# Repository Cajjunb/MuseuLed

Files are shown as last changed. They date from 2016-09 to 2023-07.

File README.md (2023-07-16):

# PCB Circuit Specification

## Description
The PCB Circuit Specification project aims to provide detailed specifications and guidelines for designing printed circuit boards (PCBs). This project covers various aspects of PCB design, including component placement, trace routing, and manufacturing considerations. The project is for a Computer Vision application and for the #ART15 fair of computer art.

## Features
- Comprehensive guidelines for PCB component placement
- Detailed trace routing specifications
- Design rules for ensuring signal integrity and minimizing noise
- Manufacturing considerations and best practices
- Sample PCB designs and case studies for reference

## Requirements
- PCB design software (e.g., Eagle, Altium Designer)
- Understanding of electronic components and circuit design principles
- Knowledge of PCB manufacturing processes

## Credits
This project is maintained by Leandro Ramalho Motta Ferreira. If you have any questions or inquiries, please contact [cajjunb@gmail.com].

## License
This project is licensed under the [MIT License](LICENSE)

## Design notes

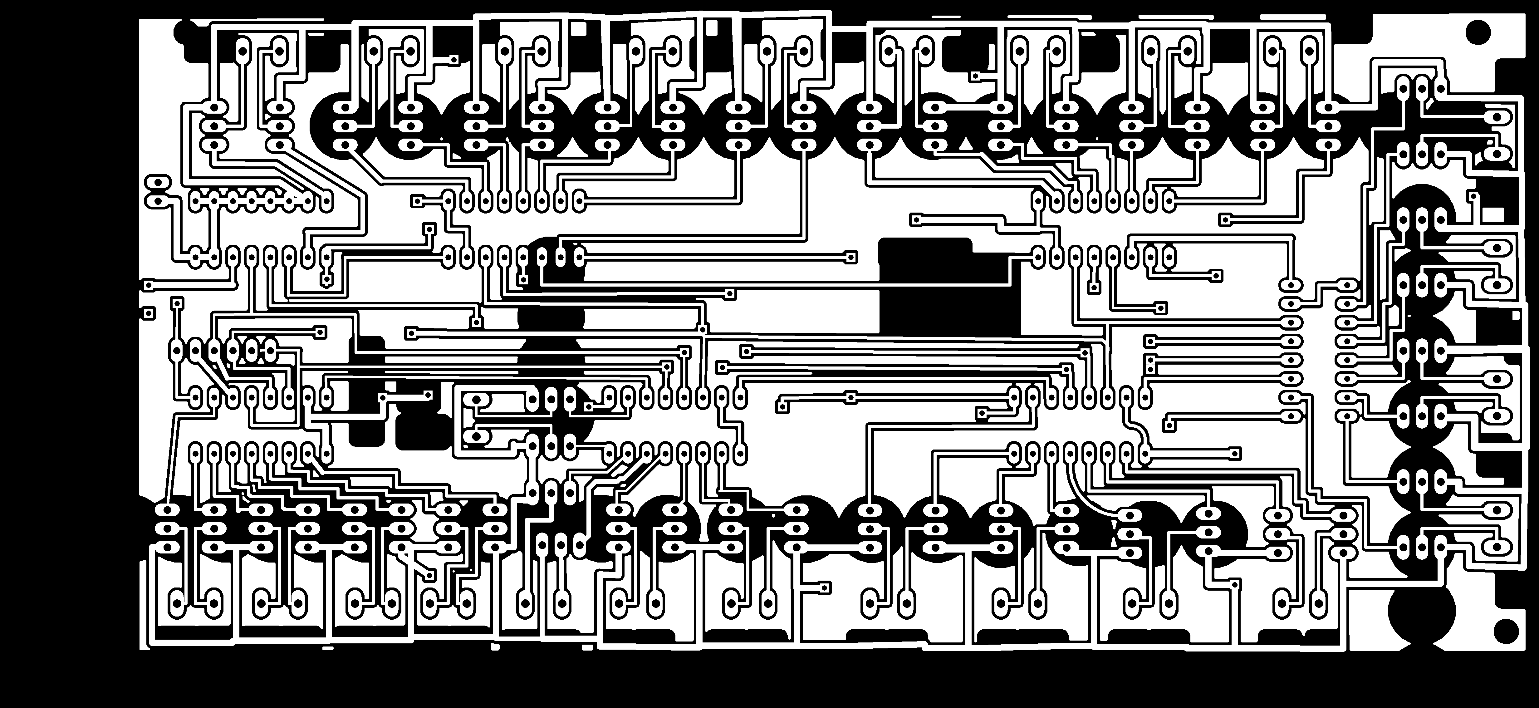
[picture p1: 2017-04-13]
circuito2/Impressão/!eagle_export.png

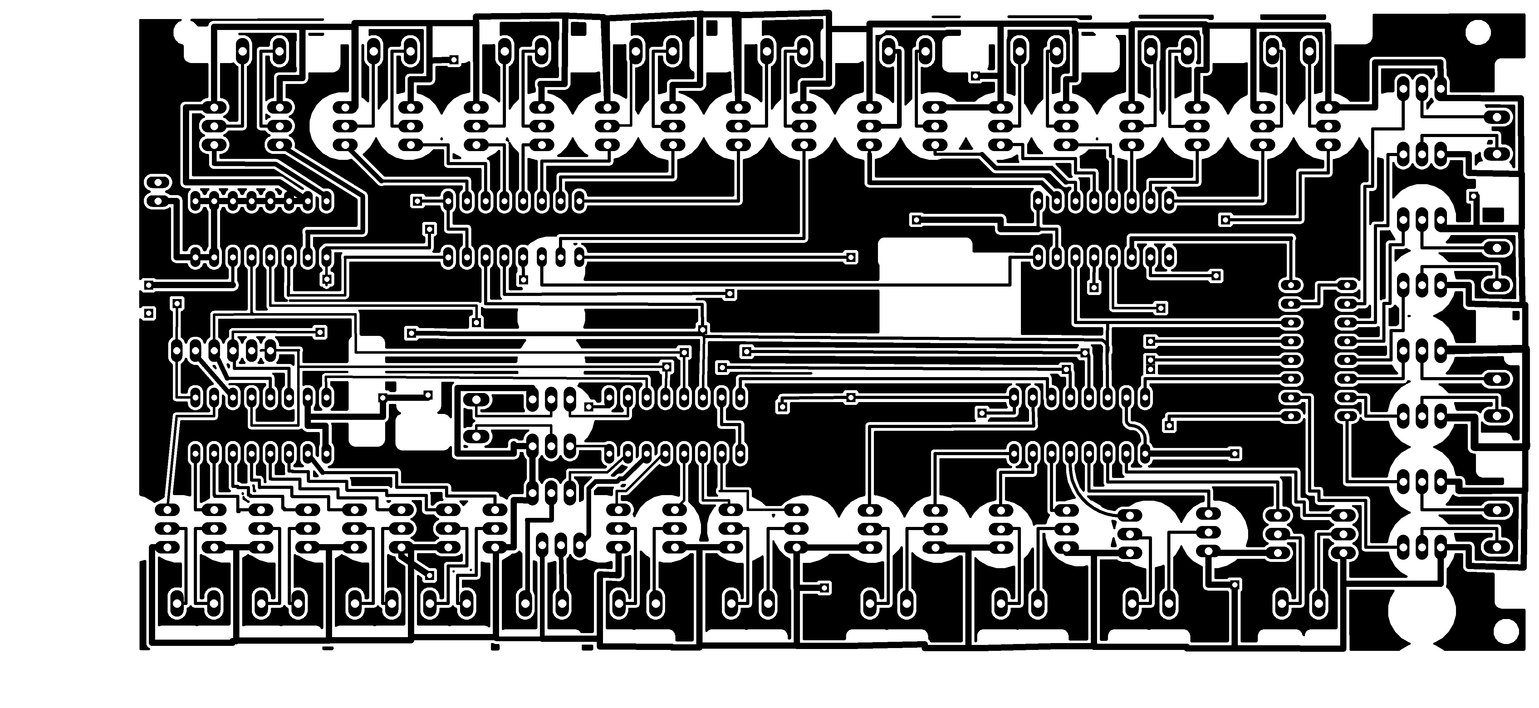
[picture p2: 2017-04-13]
circuito2/Impressão/eagle_exportNeg.jpg

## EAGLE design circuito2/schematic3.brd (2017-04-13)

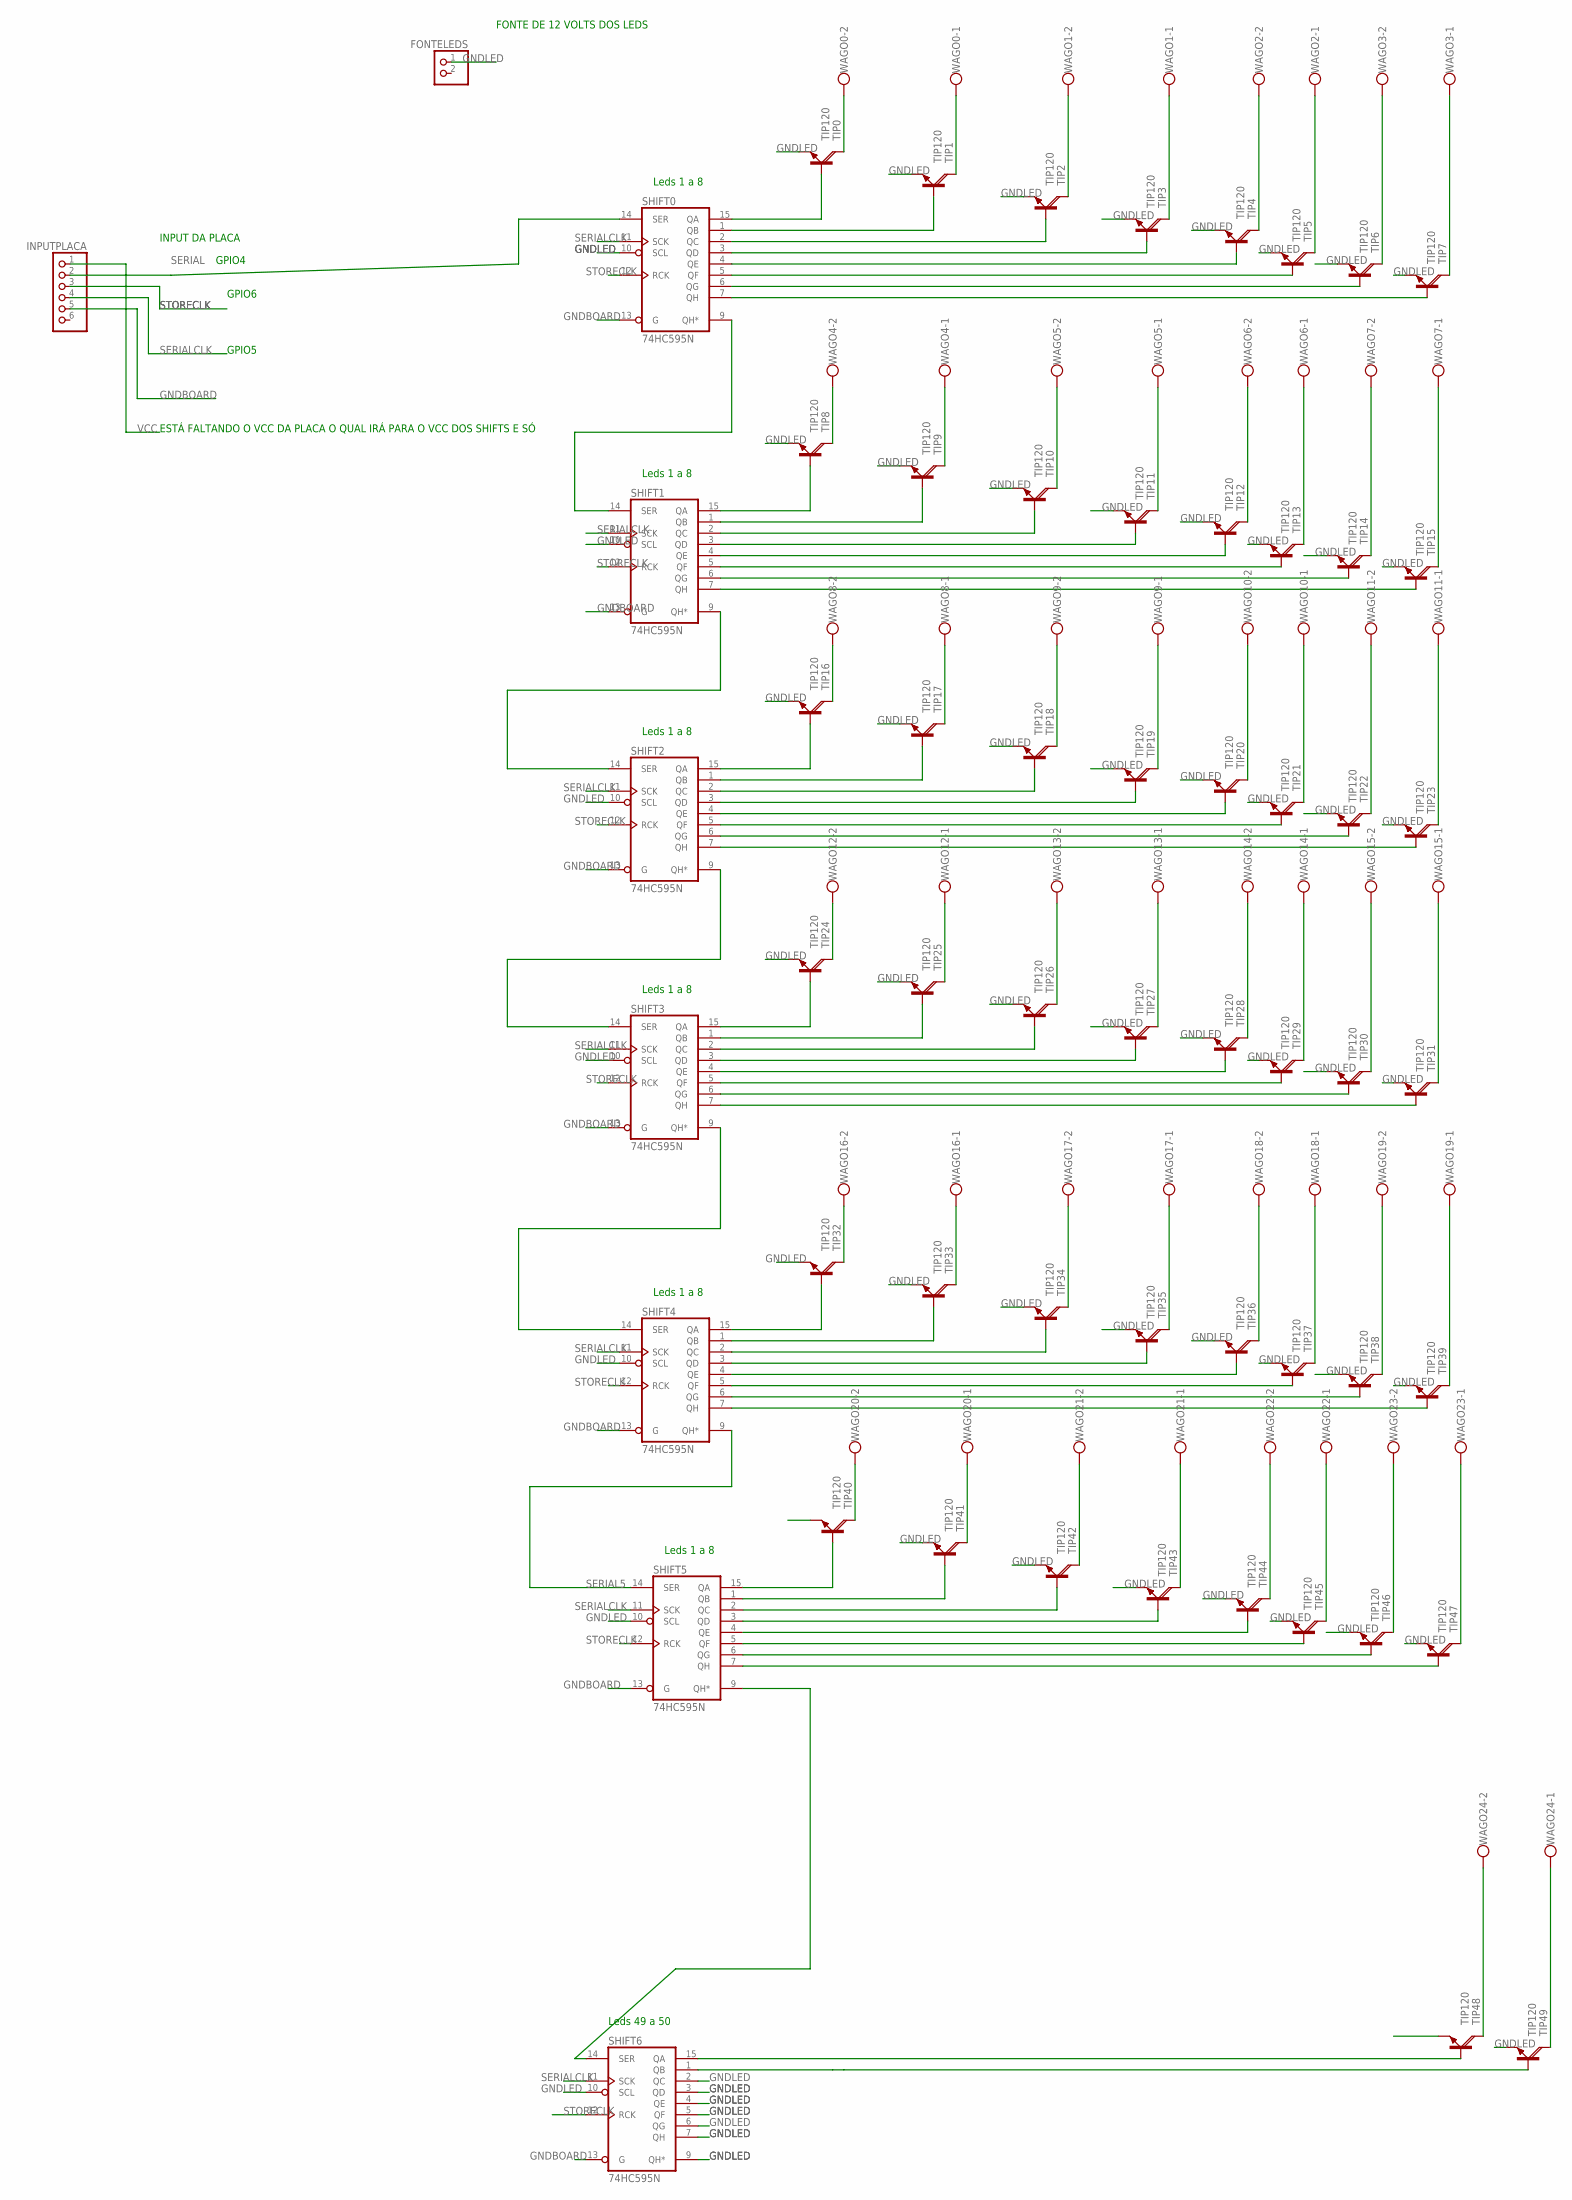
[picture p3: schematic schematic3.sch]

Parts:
FONTELEDS: PINHD-1X2; 1X02
INPUTPLACA: PINHD-1X6; 1X06
SHIFT0, SHIFT1, SHIFT2, SHIFT3, SHIFT4, SHIFT5, SHIFT6: 74HC595N; DIL16
TIP0, TIP1, TIP2, TIP3, TIP4, TIP5, TIP6, TIP7, TIP8, TIP9, TIP10, TIP11, TIP12, TIP13, TIP14, TIP15, TIP16, TIP17, TIP18, TIP19, TIP20, TIP21, TIP22, TIP23, TIP24, TIP25, TIP26, TIP27, TIP28, TIP29, TIP30, TIP31, TIP32, TIP33, TIP34, TIP35, TIP36, TIP37, TIP38, TIP39, TIP40, TIP41, TIP42, TIP43, TIP44, TIP45, TIP46, TIP47, TIP48, TIP49: TIP120; TO220AH
WAGO0, WAGO1, WAGO2, WAGO3, WAGO4, WAGO5, WAGO6, WAGO7, WAGO8, WAGO9, WAGO10, WAGO11, WAGO12, WAGO13, WAGO14, WAGO15, WAGO16, WAGO17, WAGO18, WAGO19, WAGO20, WAGO21, WAGO22, WAGO23, WAGO24: W237-102

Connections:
unnamed: SHIFT0.15 (QA), TIP0.B
unnamed: SHIFT0.1 (QB), TIP1.B
unnamed: SHIFT0.2 (QC), TIP2.B
unnamed: SHIFT0.3 (QD), TIP3.B
unnamed: SHIFT0.4 (QE), TIP4.B
unnamed: SHIFT0.5 (QF), TIP5.B
unnamed: SHIFT0.6 (QG), TIP6.B
unnamed: SHIFT0.7 (QH), TIP7.B
unnamed: SHIFT1.15 (QA), TIP8.B
unnamed: SHIFT1.1 (QB), TIP9.B
unnamed: SHIFT6.15 (QA), TIP48.B
unnamed: SHIFT1.2 (QC), TIP10.B
unnamed: SHIFT4.5 (QF), TIP37.B
unnamed: SHIFT1.3 (QD), TIP11.B
unnamed: SHIFT1.4 (QE), TIP12.B
unnamed: SHIFT4.6 (QG), TIP38.B
unnamed: SHIFT1.5 (QF), TIP13.B
unnamed: SHIFT4.7 (QH), TIP39.B
unnamed: SHIFT1.6 (QG), TIP14.B
unnamed: SHIFT5.5 (QF), TIP45.B
unnamed: SHIFT1.7 (QH), TIP15.B
unnamed: TIP8.C, WAGO4.2
unnamed: TIP9.C, WAGO4.1
unnamed: TIP10.C, WAGO5.2
unnamed: TIP11.C, WAGO5.1
unnamed: TIP12.C, WAGO6.2
unnamed: TIP13.C, WAGO6.1
unnamed: TIP14.C, WAGO7.2
unnamed: TIP15.C, WAGO7.1
unnamed: SHIFT2.15 (QA), TIP16.B
unnamed: SHIFT2.1 (QB), TIP17.B
unnamed: SHIFT2.2 (QC), TIP18.B
unnamed: SHIFT2.3 (QD), TIP19.B
unnamed: SHIFT2.4 (QE), TIP20.B
unnamed: SHIFT2.5 (QF), TIP21.B
unnamed: SHIFT2.6 (QG), TIP22.B
unnamed: SHIFT2.7 (QH), TIP23.B
unnamed: TIP16.C, WAGO8.2
unnamed: TIP17.C, WAGO8.1
unnamed: TIP18.C, WAGO9.2
unnamed: TIP19.C, WAGO9.1
unnamed: TIP20.C, WAGO10.2
unnamed: TIP21.C, WAGO10.1
unnamed: SHIFT4.15 (QA), TIP32.B
unnamed: TIP23.C, WAGO11.1
unnamed: SHIFT3.15 (QA), TIP24.B
unnamed: SHIFT3.1 (QB), TIP25.B
unnamed: SHIFT3.2 (QC), TIP26.B
unnamed: SHIFT3.3 (QD), TIP27.B
unnamed: SHIFT3.4 (QE), TIP28.B
unnamed: SHIFT5.6 (QG), TIP46.B
unnamed: SHIFT5.7 (QH), TIP47.B
unnamed: TIP0.C, WAGO0.2
unnamed: SHIFT3.5 (QF), TIP29.B
unnamed: SHIFT3.6 (QG), TIP30.B
unnamed: SHIFT3.7 (QH), TIP31.B
unnamed: TIP24.C, WAGO12.2
unnamed: TIP25.C, WAGO12.1
unnamed: TIP26.C, WAGO13.2
unnamed: SHIFT4.1 (QB), TIP33.B
unnamed: SHIFT4.2 (QC), TIP34.B
unnamed: SHIFT5.9 (QH*), SHIFT6.14 (SER)
unnamed: TIP29.C, WAGO14.1
unnamed: TIP30.C, WAGO15.2
unnamed: TIP31.C, WAGO15.1
unnamed: SHIFT4.3 (QD), TIP35.B
unnamed: SHIFT4.4 (QE), TIP36.B
unnamed: TIP1.C, WAGO0.1
unnamed: TIP2.C, WAGO1.2
unnamed: TIP32.C, WAGO16.2
unnamed: TIP3.C, WAGO1.1
unnamed: TIP33.C, WAGO16.1
unnamed: TIP34.C, WAGO17.2
unnamed: TIP37.C, WAGO18.1
unnamed: TIP38.C, WAGO19.2
unnamed: TIP39.C, WAGO19.1
unnamed: SHIFT5.15 (QA), TIP40.B
unnamed: SHIFT5.1 (QB), TIP41.B
unnamed: SHIFT5.2 (QC), TIP42.B
unnamed: SHIFT5.3 (QD), TIP43.B
unnamed: SHIFT5.4 (QE), TIP44.B
unnamed: TIP40.C, WAGO20.2
unnamed: TIP41.C, WAGO20.1
unnamed: TIP42.C, WAGO21.2
unnamed: TIP45.C, WAGO22.1
unnamed: TIP46.C, WAGO23.2
unnamed: TIP47.C, WAGO23.1
unnamed: TIP48.C, WAGO24.2
unnamed: TIP49.C, WAGO24.1
unnamed: SHIFT6.1 (QB), TIP49.B
unnamed: TIP4.C, WAGO2.2
unnamed: TIP5.C, WAGO2.1
unnamed: TIP6.C, WAGO3.2
unnamed: TIP7.C, WAGO3.1
SERIAL: INPUTPLACA.2, SHIFT0.14 (SER)
SERIAL1: SHIFT0.9 (QH*), SHIFT1.14 (SER)
SERIAL2: SHIFT1.9 (QH*), SHIFT2.14 (SER)
SERIAL3: SHIFT2.9 (QH*), SHIFT3.14 (SER)
SERIAL4: SHIFT3.9 (QH*), SHIFT4.14 (SER)
SERIAL5: SHIFT4.9 (QH*), SHIFT5.14 (SER)
SERIALCLK: INPUTPLACA.4, SHIFT0.11 (SCK), SHIFT1.11 (SCK), SHIFT2.11 (SCK), SHIFT3.11 (SCK), SHIFT4.11 (SCK), SHIFT5.11 (SCK), SHIFT6.11 (SCK)
STORECLK: INPUTPLACA.3, SHIFT0.12 (RCK), SHIFT1.12 (RCK), SHIFT2.12 (RCK), SHIFT3.12 (RCK), SHIFT4.12 (RCK), SHIFT5.12 (RCK), SHIFT6.12 (RCK)
VCC: INPUTPLACA.1, SHIFT0.16 (VCC), SHIFT1.16 (VCC), SHIFT2.16 (VCC), SHIFT3.16 (VCC), SHIFT4.16 (VCC), SHIFT5.16 (VCC), SHIFT6.16 (VCC)
WAGO1: TIP35.C, WAGO17.1
WAGO2: TIP36.C, WAGO18.2
WAGO3: TIP43.C, WAGO21.1
WAGO4: TIP44.C, WAGO22.2
WAGO11: TIP22.C, WAGO11.2
WAGO14: TIP27.C, WAGO13.1
WAGO15: TIP28.C, WAGO14.2

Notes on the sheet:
Leds 1 a 8
Leds 49 a 50
FONTE DE 12 VOLTS DOS LEDS
INPUT DA PLACA
ESTÁ FALTANDO O VCC DA PLACA O QUAL IRÁ PARA O VCC DOS SHIFTS E SÓ
GPIO4
GPIO6
GPIO5

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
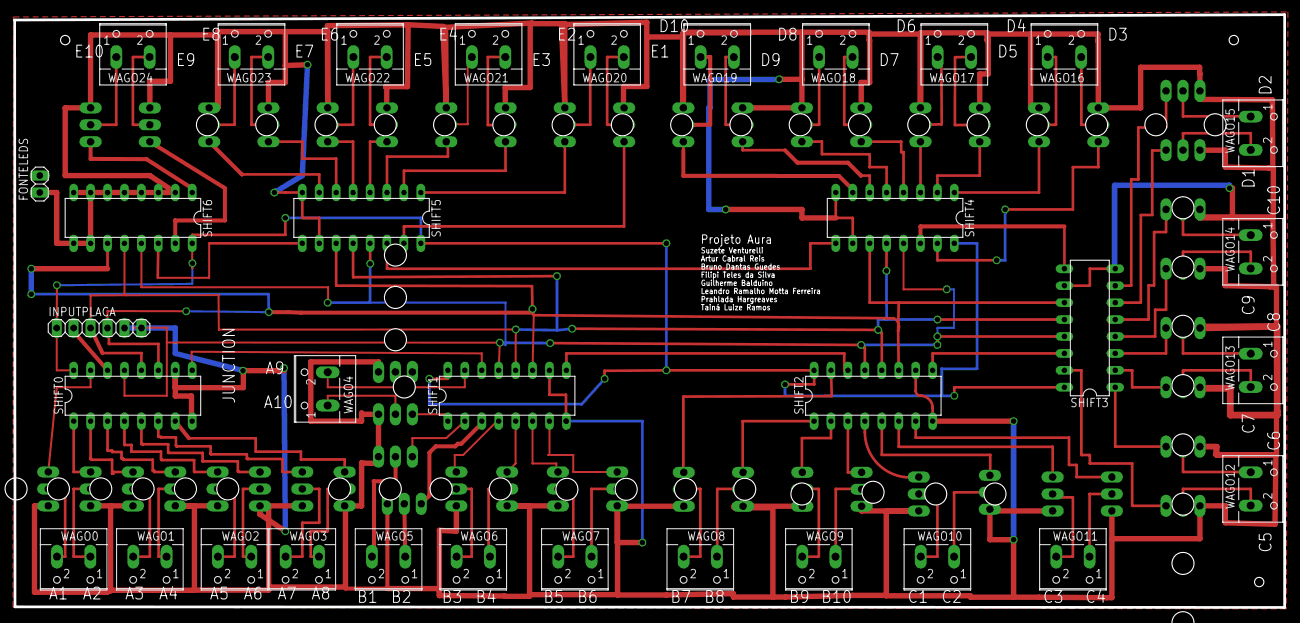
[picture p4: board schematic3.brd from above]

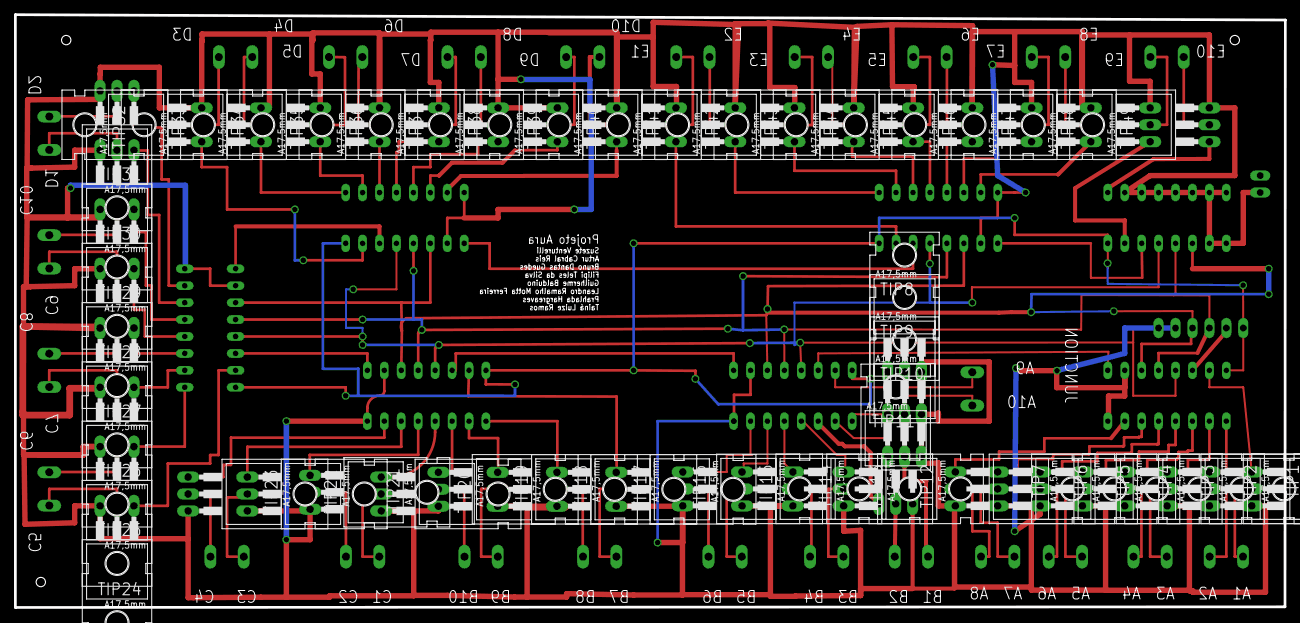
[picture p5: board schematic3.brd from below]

Board: 2 copper layers, 190.5 x 88.9 mm, 84 parts (50 on the bottom side), 112 nets.

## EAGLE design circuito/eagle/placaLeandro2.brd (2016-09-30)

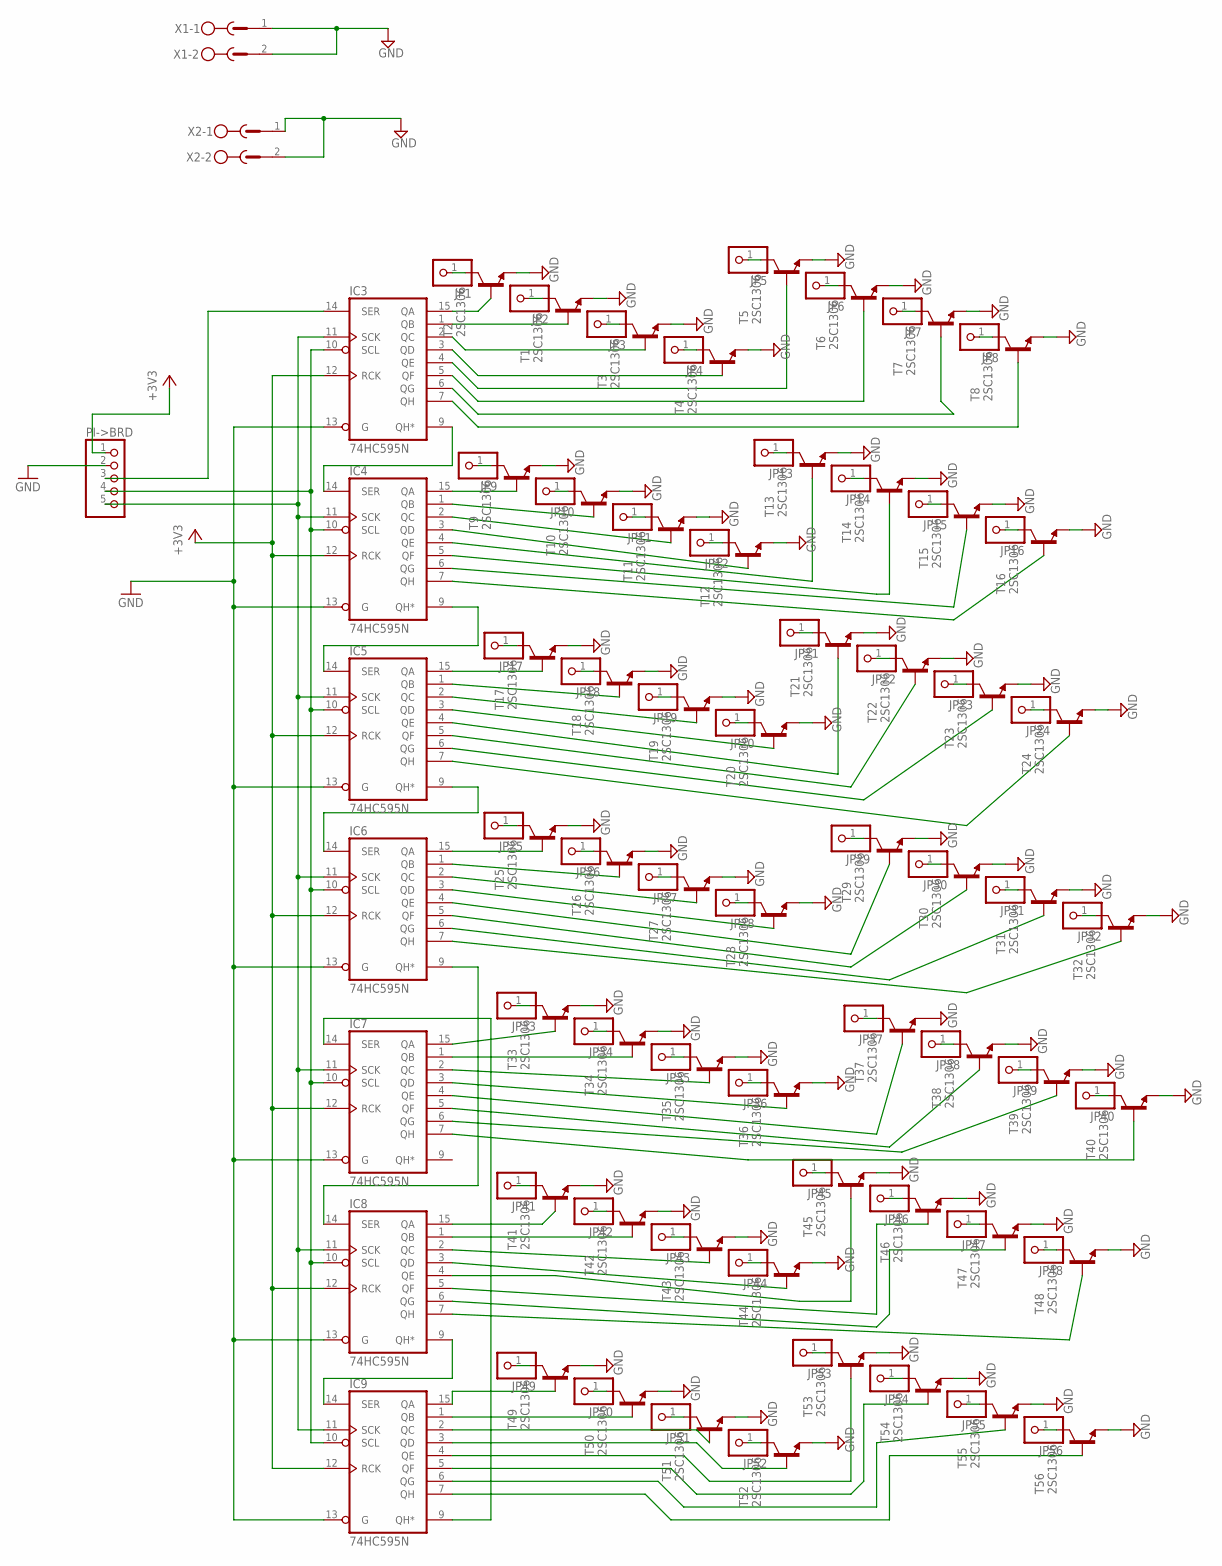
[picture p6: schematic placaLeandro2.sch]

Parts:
IC3, IC4, IC5, IC6, IC7, IC8, IC9: 74HC595N; DIL16
JP1, JP2, JP3, JP4, JP5, JP6, JP7, JP8, JP9, JP10, JP11, JP12, JP13, JP14, JP15, JP16, JP17, JP18, JP19, JP20, JP21, JP22, JP23, JP24, JP25, JP26, JP27, JP28, JP29, JP30, JP31, JP32, JP33, JP34, JP35, JP36, JP37, JP38, JP39, JP40, JP41, JP42, JP43, JP44, JP45, JP46, JP47, JP48, JP49, JP50, JP51, JP52, JP53, JP54, JP55, JP56: PINHD-1X1; 1X01
PI->BRD: PINHD-1X5; 1X05
T1, T2, T3, T4, T5, T6, T7, T8, T9, T10, T11, T12, T13, T14, T15, T16, T17, T18, T19, T20, T21, T22, T23, T24, T25, T26, T27, T28, T29, T30, T31, T32, T33, T34, T35, T36, T37, T38, T39, T40, T41, T42, T43, T44, T45, T46, T47, T48, T49, T50, T51, T52, T53, T54, T55, T56: 2SC1306; TO220BV
X1, X2: MSTBV2

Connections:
+3V3: IC3.12 (RCK), IC4.12 (RCK), IC5.12 (RCK), IC6.12 (RCK), IC7.12 (RCK), IC8.12 (RCK), IC9.12 (RCK), PI->BRD.1
GND: IC3.8 (GND), IC3.13 (G), IC4.8 (GND), IC4.13 (G), IC5.8 (GND), IC5.13 (G), IC6.8 (GND), IC6.13 (G), IC7.8 (GND), IC7.13 (G), IC8.8 (GND), IC8.13 (G), IC9.8 (GND), IC9.13 (G), PI->BRD.2, T1.3 (E), T2.3 (E), T3.3 (E), T4.3 (E), T5.3 (E), T6.3 (E), T7.3 (E), T8.3 (E), T9.3 (E), T10.3 (E), T11.3 (E), T12.3 (E), T13.3 (E), T14.3 (E), T15.3 (E), T16.3 (E), T17.3 (E), T18.3 (E), T19.3 (E), T20.3 (E), T21.3 (E), T22.3 (E), T23.3 (E), T24.3 (E), T25.3 (E), T26.3 (E), T27.3 (E), T28.3 (E), T29.3 (E), T30.3 (E), T31.3 (E), T32.3 (E), T33.3 (E), T34.3 (E), T35.3 (E), T36.3 (E), T37.3 (E), T38.3 (E), T39.3 (E), T40.3 (E), T41.3 (E), T42.3 (E), T43.3 (E), T44.3 (E), T45.3 (E), T46.3 (E), T47.3 (E), T48.3 (E), T49.3 (E), T50.3 (E), T51.3 (E), T52.3 (E), T53.3 (E), T54.3 (E), T55.3 (E), T56.3 (E), X1.1, X1.2, X2.1, X2.2
unnamed: IC6.9 (QH*), IC8.14 (SER)
unnamed: IC3.9 (QH*), IC4.14 (SER)
unnamed: IC4.9 (QH*), IC5.14 (SER)
unnamed: IC5.9 (QH*), IC6.14 (SER)
unnamed: IC8.9 (QH*), IC9.14 (SER)
unnamed: IC7.14 (SER), IC9.9 (QH*)
unnamed: IC3.11 (SCK), IC4.11 (SCK), IC5.11 (SCK), IC6.11 (SCK), IC7.11 (SCK), IC8.11 (SCK), IC9.11 (SCK), PI->BRD.5
unnamed: IC3.10 (SCL), IC4.10 (SCL), IC5.10 (SCL), IC6.10 (SCL), IC7.10 (SCL), IC8.10 (SCL), IC9.10 (SCL), PI->BRD.4
unnamed: JP1.1, T2.2 (C)
unnamed: JP2.1, T1.2 (C)
unnamed: JP3.1, T3.2 (C)
unnamed: IC3.14 (SER), PI->BRD.3
unnamed: JP4.1, T4.2 (C)
unnamed: JP5.1, T5.2 (C)
unnamed: JP6.1, T6.2 (C)
unnamed: JP7.1, T7.2 (C)
unnamed: JP8.1, T8.2 (C)
unnamed: JP9.1, T9.2 (C)
unnamed: JP10.1, T10.2 (C)
unnamed: JP11.1, T11.2 (C)
unnamed: JP12.1, T12.2 (C)
unnamed: JP13.1, T13.2 (C)
unnamed: JP14.1, T14.2 (C)
unnamed: JP15.1, T15.2 (C)
unnamed: JP16.1, T16.2 (C)
unnamed: JP17.1, T17.2 (C)
unnamed: JP18.1, T18.2 (C)
unnamed: JP19.1, T19.2 (C)
unnamed: JP20.1, T20.2 (C)
unnamed: JP21.1, T21.2 (C)
unnamed: JP22.1, T22.2 (C)
unnamed: JP23.1, T23.2 (C)
unnamed: JP24.1, T24.2 (C)
unnamed: JP25.1, T25.2 (C)
unnamed: JP26.1, T26.2 (C)
unnamed: JP27.1, T27.2 (C)
unnamed: JP28.1, T28.2 (C)
unnamed: JP29.1, T29.2 (C)
unnamed: JP30.1, T30.2 (C)
unnamed: JP31.1, T31.2 (C)
unnamed: JP32.1, T32.2 (C)
unnamed: JP33.1, T33.2 (C)
unnamed: JP34.1, T34.2 (C)
unnamed: JP35.1, T35.2 (C)
unnamed: JP36.1, T36.2 (C)
unnamed: JP37.1, T37.2 (C)
unnamed: JP38.1, T38.2 (C)
unnamed: JP39.1, T39.2 (C)
unnamed: JP40.1, T40.2 (C)
unnamed: JP41.1, T41.2 (C)
unnamed: JP42.1, T42.2 (C)
unnamed: JP43.1, T43.2 (C)
unnamed: JP44.1, T44.2 (C)
unnamed: JP45.1, T45.2 (C)
unnamed: JP46.1, T46.2 (C)
unnamed: JP47.1, T47.2 (C)
unnamed: JP48.1, T48.2 (C)
unnamed: JP49.1, T49.2 (C)
unnamed: JP50.1, T50.2 (C)
unnamed: JP51.1, T51.2 (C)
unnamed: JP52.1, T52.2 (C)
unnamed: JP53.1, T53.2 (C)
unnamed: JP54.1, T54.2 (C)
unnamed: JP55.1, T55.2 (C)
unnamed: JP56.1, T56.2 (C)
unnamed: IC3.1 (QB), T1.1 (B)
unnamed: IC3.2 (QC), T3.1 (B)
unnamed: IC3.3 (QD), T4.1 (B)
unnamed: IC3.4 (QE), T5.1 (B)
unnamed: IC3.5 (QF), T6.1 (B)
unnamed: IC3.6 (QG), T7.1 (B)
unnamed: IC3.7 (QH), T8.1 (B)
unnamed: IC4.15 (QA), T9.1 (B)
unnamed: IC4.1 (QB), T10.1 (B)
unnamed: IC4.2 (QC), T11.1 (B)
unnamed: IC4.3 (QD), T12.1 (B)
unnamed: IC4.4 (QE), T13.1 (B)
unnamed: IC4.5 (QF), T14.1 (B)
unnamed: IC4.6 (QG), T15.1 (B)
unnamed: IC4.7 (QH), T16.1 (B)
unnamed: IC5.15 (QA), T17.1 (B)
unnamed: IC5.1 (QB), T18.1 (B)
unnamed: IC5.2 (QC), T19.1 (B)
unnamed: IC5.3 (QD), T20.1 (B)
unnamed: IC5.4 (QE), T21.1 (B)
unnamed: IC5.5 (QF), T22.1 (B)
unnamed: IC5.6 (QG), T23.1 (B)
unnamed: IC5.7 (QH), T24.1 (B)
unnamed: IC6.15 (QA), T25.1 (B)
unnamed: IC6.1 (QB), T26.1 (B)
unnamed: IC6.2 (QC), T27.1 (B)
unnamed: IC6.3 (QD), T28.1 (B)
unnamed: IC6.4 (QE), T29.1 (B)
unnamed: IC6.5 (QF), T30.1 (B)
unnamed: IC6.6 (QG), T31.1 (B)
unnamed: IC6.7 (QH), T32.1 (B)
unnamed: IC7.15 (QA), T33.1 (B)
unnamed: IC7.1 (QB), T34.1 (B)
unnamed: IC7.2 (QC), T35.1 (B)
unnamed: IC7.3 (QD), T36.1 (B)
unnamed: IC7.4 (QE), T37.1 (B)
unnamed: IC7.5 (QF), T38.1 (B)
unnamed: IC7.6 (QG), T39.1 (B)
unnamed: IC7.7 (QH), T40.1 (B)
unnamed: IC8.15 (QA), T41.1 (B)
unnamed: IC8.1 (QB), T42.1 (B)
unnamed: IC8.2 (QC), T43.1 (B)
unnamed: IC8.3 (QD), T44.1 (B)
unnamed: IC8.4 (QE), T45.1 (B)
unnamed: IC8.5 (QF), T46.1 (B)
unnamed: IC8.6 (QG), T47.1 (B)
unnamed: IC8.7 (QH), T48.1 (B)
unnamed: IC9.15 (QA), T49.1 (B)
unnamed: IC9.1 (QB), T50.1 (B)
unnamed: IC9.2 (QC), T51.1 (B)
unnamed: IC9.3 (QD), T52.1 (B)
unnamed: IC9.4 (QE), T53.1 (B)
unnamed: IC9.5 (QF), T54.1 (B)
unnamed: IC9.6 (QG), T55.1 (B)
unnamed: IC9.7 (QH), T56.1 (B)
unnamed: IC3.15 (QA), T2.1 (B)
VCC: IC3.16 (VCC), IC4.16 (VCC), IC5.16 (VCC), IC6.16 (VCC), IC7.16 (VCC), IC8.16 (VCC), IC9.16 (VCC)

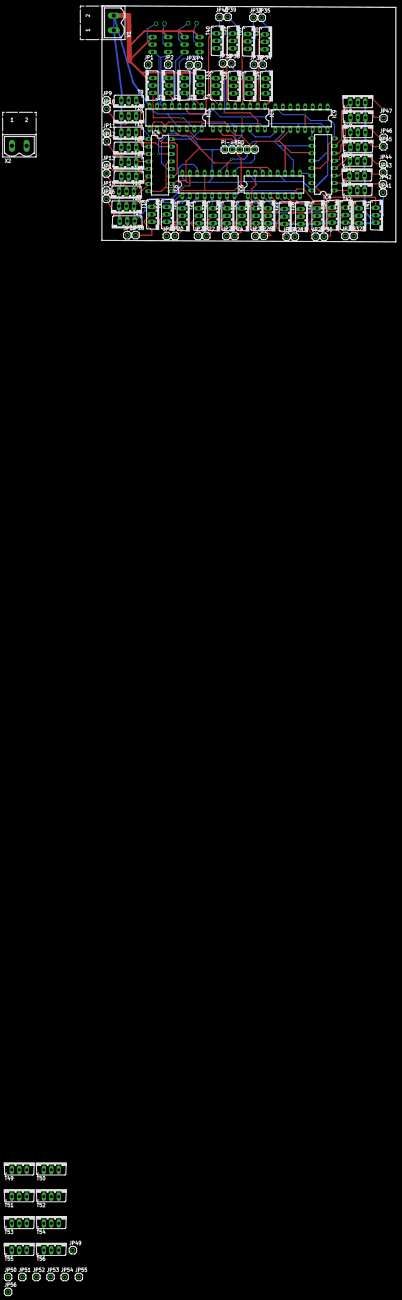
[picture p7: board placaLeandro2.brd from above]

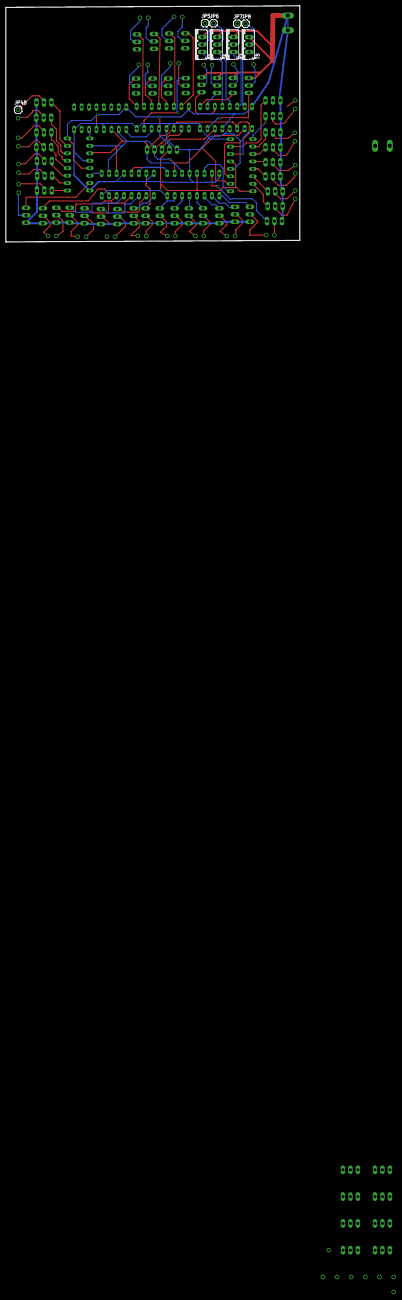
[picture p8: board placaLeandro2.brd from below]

Board: 2 copper layers, 100.3 x 80.5 mm, 122 parts (9 on the bottom side), 124 nets.

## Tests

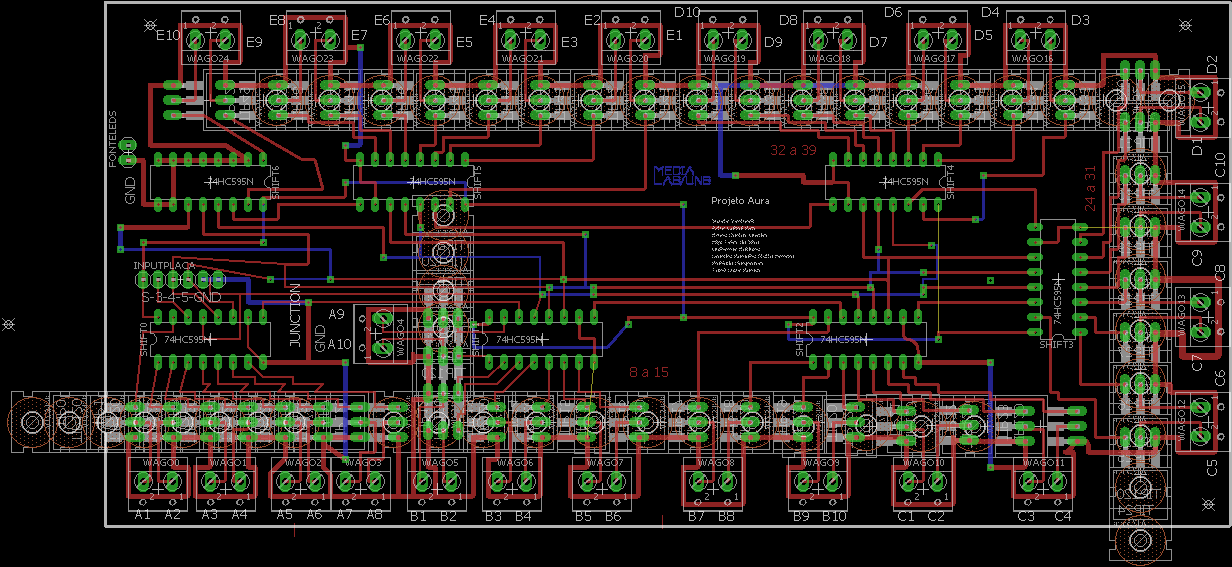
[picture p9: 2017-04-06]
circuito2/imagemTeste.png

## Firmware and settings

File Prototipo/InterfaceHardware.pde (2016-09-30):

import processing.io.*;

// Classe que serve como interface para os pinos do raspberry
// faz o tratamento. Implementacao do clock e do protocolo de acender os LEDS
class HardwareInterface  {
  
  public  boolean[] dataOutput;
  private int limiteBits;
  
  //Construtor default
  HardwareInterface(){
    this.dataOutput = new boolean[50];
    this.limiteBits = 50;    
  }

  //Construtor que vem o limite de shift register
  HardwareInterface(int limite){
    print("\t INSTANCIEI!!!\n"); 
    noLoop();
    this.dataOutput = new boolean[limite];
    this.limiteBits = limite;
    
  }
  //Output toda a data que ira no registrador
  boolean mandaTodaData(){
    int bitAux;
    int i;
    //GPIO.digitalWrite(5,GPIO.LOW);
    for(i = this.limiteBits-1;  i >= 0 ; i--){
      //Faz o output e faz a transicao do clock
      bitAux = (this.dataOutput[i]) ? GPIO.HIGH : GPIO.LOW;
      GPIO.digitalWrite(4,bitAux);
      //CLOCK0 TRANSICAO HIGH LOW 
      //if(i != this.limiteBits-1){
        GPIO.digitalWrite(5,GPIO.HIGH);
        GPIO.digitalWrite(5,GPIO.LOW);
      //}       
    }
    print("\tFim LOOP\n");
    //Aciona o latch para mandar isso
    
    GPIO.digitalWrite(6,GPIO.HIGH);
    GPIO.digitalWrite(6,GPIO.LOW);  
  if(i == this.limiteBits)
    return true;
  else
    return false;
  }
}

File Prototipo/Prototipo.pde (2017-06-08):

ArrayList<Cell> cells;
ArrayList<Cell> cellsAlive;
ArrayList<Cell> comidas;

int LARGURA = 10;
int ALTURA = 5;

//Camera Objeot
cameraInput camera;
//INTERFACE DE HARDWARE
HardwareInterface objetoInterface;
//FLUXO DE CADA CELULA
float fluxoAmbiente[][][];

int delayFlag = 0;

void delayDuasVezes(){
  print("\t################### DELAY! ##############\n");
  noLoop();
  delay(15000);
  delayFlag++;
  loop();
}

/* ################################ SETUP #############################*/
void setup(){
  try{
      print("\t###################ANTES DE EXCEPTION!####################\n");
      GPIO.pinMode(4, GPIO.OUTPUT);
      GPIO.pinMode(5, GPIO.OUTPUT);
      GPIO.pinMode(6, GPIO.OUTPUT);    
     }catch(Exception e){
      print("\t###################EXCEPTION!####################\n");
      GPIO.pinMode(4, GPIO.OUTPUT);
      GPIO.pinMode(5, GPIO.OUTPUT);
      GPIO.pinMode(6, GPIO.OUTPUT);  
  }
  size(625, 625,P3D);
  noLoop();
  smooth();
  frameRate(10);
  colorMode(HSB, 360, 100, 100);
 
  
  //Instancia o controlador da camera 
  camera = new cameraInput(this);
  //instanciando o vetor FLuxo
  fluxoAmbiente = new float[ALTURA][LARGURA][2];
  // Instanciando uma celula de fronteira 
  Cell celulaFronteira = new Cell(true);
  //Instanciando Arrays de Celulas
  Cell[][] cellArray = new Cell[ALTURA][LARGURA];
  for(int y = 0; y < ALTURA; y++){
    for(int x = 0; x < LARGURA; x++){
      //if((y % 2 == 0 && x % 2 == 0) || (y % 2 == 1 && x % 2 == 1)){
        PVector pos = new PVector(x * LARGURA, y * ALTURA);
        cellArray[y][x] = new Cell(pos);
        cellArray[y][x].index =  (y*LARGURA) +x;
      //}
    }
  }
  /*####################### SETANDO ARRAYS GLOBAIS ###############*/
  cells = new ArrayList<Cell>();
  comidas = new ArrayList<Cell>();
  cellsAlive = new ArrayList<Cell>();
  /*####################### SETANDO ARRAYS GLOBAIS ###############*/
  for(int y = 0; y < ALTURA; y++){
    for(int x = 0; x < LARGURA; x++){
      //if((y % 2 == 0 && x % 2 == 0) || (y % 2 == 1 && x % 2 == 1)){
        Cell cell = cellArray[y][x];
        cells.add(cell);
        //Adicionando vizinhos as celulas
        if( x > 0){
          //Vizinho da esquerda
          cell.addToNeighbors(cellArray[y][x-1]);
        }else
          cell.addToNeighbors(celulaFronteira);
        if(x < LARGURA-1){
          //Vizinho da direita
          cell.addToNeighbors(cellArray[y][x+1]);
        }else
          cell.addToNeighbors(celulaFronteira);
        if( y > 0){
          //Vizinho de cima
          cell.addToNeighbors(cellArray[y-1][x]);
        }else
          cell.addToNeighbors(celulaFronteira);
        if(y < ALTURA-1){
          //Vizinho de baixo
          cell.addToNeighbors(cellArray[y+1][x]);
        }else
          cell.addToNeighbors(celulaFronteira);
    }
  }
  registerMethod("pre", this);
  cells.get(22).fillUpEnergy();
  //INTERFACE COM OS LEDS
  objetoInterface = new HardwareInterface(50);
  loop();
}
 
/*############################## DRAW *********************************/
void draw(){
  //Delay
  /*while(delayFlag < 3)
    delayDuasVezes();
  */
  background(0, 0, 10); 
  for(Cell cell: cells){
    //Atualiza o valor se estiver vivo
    objetoInterface.dataOutput[cell.index] = (cell.estaVivo) ? true : false;
    cell.display();
  }
  
  objetoInterface.mandaTodaData();
  //camera Objeto desenha os frames da camera
  camera.desenhaCamera();
}


/*######################## Controladora de toda a logica da simulação #######################*/
void pre(){
  int aux = int(random(cells.size()));
  int auxPixel ;
  int random ;  
  boolean flagMovimento = false;
  /*CALCULA o fluxo da imagem, depois retorna para ser usada para as células se movimentarem */
  camera.calculaFluxoOpenCV(ALTURA,LARGURA);
  fluxoAmbiente = camera.getFluxoAmbiente();
  for(int i = 0; i < ALTURA; ++i){
      for(int j =0 ; j < LARGURA; ++j){
          float valorU = fluxoAmbiente[i][j][0];
          float valorV = fluxoAmbiente[i][j][1];
          float angulo = asin(valorU/sqrt(valorU*valorU+valorV*valorV))+PI/2;
          int pos = i*LARGURA +j;
          if(abs(valorU) > 0 || abs(valorV) > 0 ){
              flagMovimento = true;
          }else{
              if(cells.get(pos).estaVivo){
                  if( angulo < 0)
                      angulo += 2*PI;
                  if(angulo > 0 && angulo <= 2*PI/8)
                     cells.get(pos).movimentaCelula(Direcao.LESTE);
                  else if(angulo > 2*PI/8 && angulo <= 2*2*PI/8)
                     cells.get(pos).movimentaCelula(Direcao.NORTE);
                  else if(angulo > 2*2*PI/8 && angulo <= 3*2*PI/8)
                     cells.get(pos).movimentaCelula(Direcao.NORTE);
                  else if(angulo > 3*2*PI/8 && angulo <= 4*2*PI/8)
                     fill(#FF6666);
                  else if(angulo > 4*2*PI/8 && angulo <= 5*2*PI/8)
                     cells.get(pos).movimentaCelula(Direcao.OESTE);
                  else if(angulo > 5*2*PI/8 && angulo <= 6*2*PI/8)
                     fill(#FFFFCC);
                  else if(angulo > 6*2*PI/8 && angulo <= 7*2*PI/8)
                     cells.get(pos).movimentaCelula(Direcao.SUL);
                  else if(angulo > 7*2*PI/8 && angulo <= 2*PI)
                     fill(#CCFFFF);
              }
          }
      }
  } 
  if(flagMovimento){
    random = int(random(cells.size())) ;
    cells.get(random).fillUpEnergy();
  }
  /*Envelhece as celulas e faz elas morrerem por inatividade*/
  for(int i = cellsAlive.size()- 1; i>=0 ; i--){
    cellsAlive.get(i).diffuseEnergy();
  }  
  /*Roda a chance de cada celula se reproduzir, tem menos q 0,1% de chance*/
  for(int i = cellsAlive.size()- 1; i>=0 ; i--){
    if(random(1000.0)<1)
      cellsAlive.get(i).reproducaoCelular();
  }
  /*Celulas farejam a comida*/
  for(int i = cellsAlive.size()- 1; i>=0 ; i--){
    cellsAlive.get(i).farejarComida();
  } 
  
  /*Celulas se movimentam aleatoriamente*/
  for(int i = cellsAlive.size()- 1; i>=0 ; i--){
    cellsAlive.get(i).movimentoRandomico();
  } 
}

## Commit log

2016-07-03 3x3 raio de difusao
2016-07-16 Resolvendo conflitos de programacao Concorrente
    [Cell.pde]
2016-08-02 Voltando de ferias, movimento randomico
2016-08-10 comecando a camera
2016-08-10 Errei e voltei agora com a camera aparecendo
2016-08-15 consegui fazer que a camera detecte diferenca entre a camera e preto
2016-08-19 commit para testar no raspberry
2016-08-26 versao que funciona ALgo no raspberry
2016-08-29 FUNCIONANDO RASPBERRY POHA
2016-09-12 fiz o primeiro sketch
    [circuitoMain.fzz]
2016-09-14 circuito verso dia 12
    [circuitoMain.fzz]
2016-09-14 coloquei os transistores em todas as saidas
    [circuitoMain.fzz]
2016-09-16 tentando fazer o circuito
    [circuitoAlternativo.fzz, circuitoMain.fzz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]
2016-09-21 circuito Finalizado falta a alimentacao dos leds
    [circuitoMain.fzz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]
2016-09-21 Circuito 2 com a bateria ja
    [circuitoMain2.fzz]
2016-09-21 Circuito feito
    [circuitoMain2.fzz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]
2016-09-26 schematic eagle!
    [circuitoMain.fzz, circuitoMain2.fzz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]
2016-09-26 segunda linha de tips
2016-09-26 circuito 2 denovo
    [placaLeandro2.brd]
2016-09-26 circuito 3 feito
    [placaLeandro2.brd]
2016-09-27 terminando o penultimo circuito
    [placaLeandro2.brd]
2016-09-29 teste de interface funcionando e o totem ta aqui
2016-09-30 VERSAO FINAL DO MUSEU NACIONAL DIA 4 de outubro de 2016
2017-03-23 terminando o circuito 2
    [schematic3.brd, schematic3.sch]
2017-03-23 parei da quitna
    [schematic3.brd]
2017-03-26 terminei quase
    [schematic3.brd, schematic3.sch]
2017-03-26 criei o outline da placa
    [schematic3.brd, schematic3.sch]
2017-03-26 endireitei as margens
    [schematic3.brd]
2017-03-26 apos calculo 22cm de largura
    [schematic3.brd]
2017-03-27 diminui para 20 cm
    [schematic3.brd, schematic3.sch]
2017-03-27 resolvido tamanho da placa
    [schematic3.brd]
2017-03-28 botei a logo e fiz uma verificacao de design
    [schematic3.brd]
2017-04-06 resolvendo a parte da impressao
    [schematic3.brd]
2017-04-06 pequenos consertos
    [schematic3.brd]
2017-04-11 Placa pos correcoes do professor do sg 11
    [schematic3.brd]
2017-04-11 mais um detalhe feito separando as ilhas
    [schematic3.brd]
2017-04-11 correçaoprahlada
    [schematic3.brd]
2017-04-11 correcoes dos airwires
    [schematic3.brd]
2017-04-13 placa versao final com ilhas maneiras
    [schematic3.brd]
